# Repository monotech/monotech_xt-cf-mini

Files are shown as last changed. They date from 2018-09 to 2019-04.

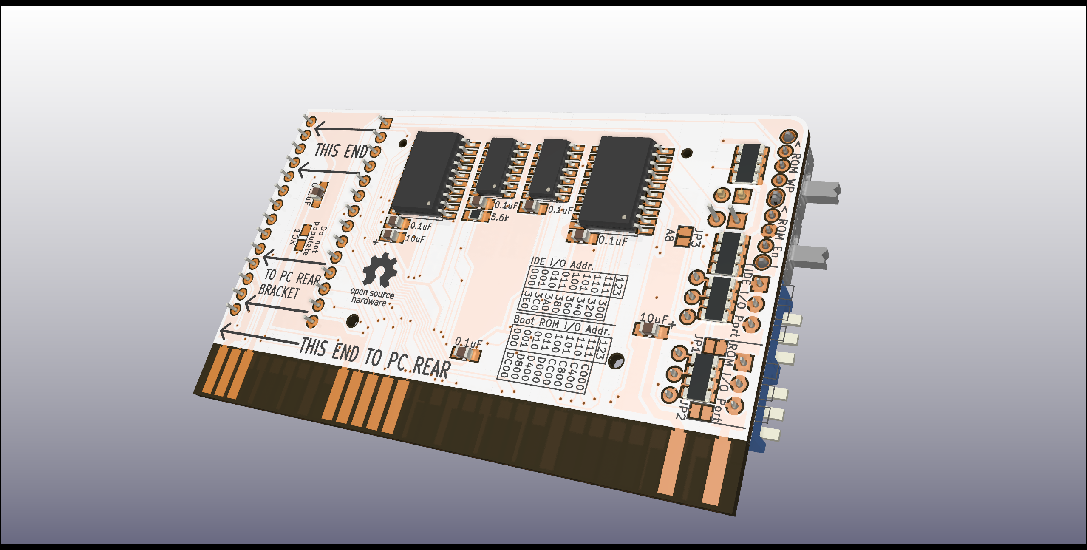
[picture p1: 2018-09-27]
Images/Rear with some parts models.png

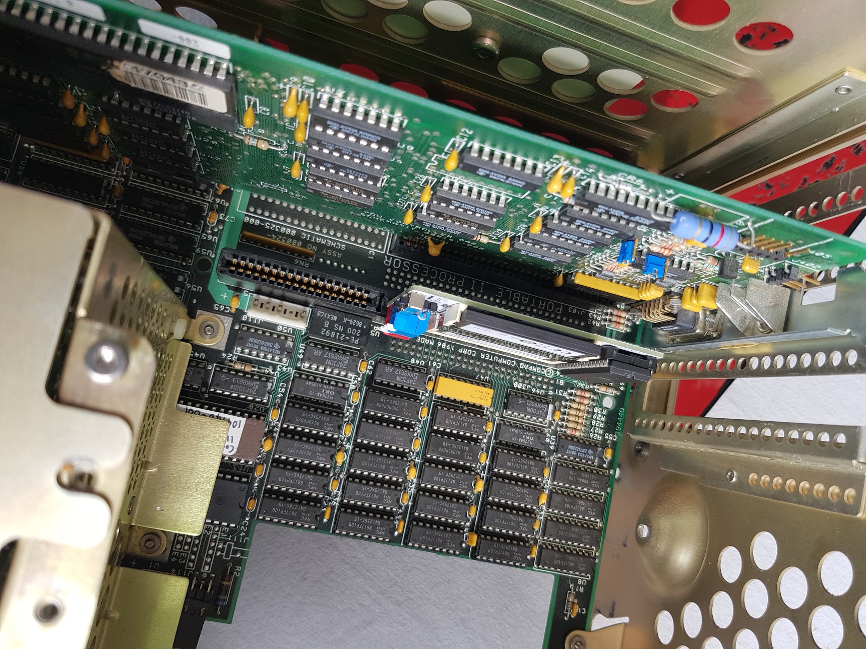
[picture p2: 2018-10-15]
Photos/In motherboard - top.jpg

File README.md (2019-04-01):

Monotech XT-CF-Mini Rev1.1 ReadMe
----------------------------

8-bit ISA CompactFlash interface + Boot ROM (two separate functions that can be used individually).

Documentation for the switches can be found on the rear silkscreen. More ROM I/O addresses are possible than the information on the silkscreen. See below.

Credit:
-------
Design uses schematic from Sergey Kiselev, with a few small changes to switches, and PCB from scratch.\
www.malinov.com/Home/sergeys-projects/xt-cf-lite

XT-IDE Universal BIOS\
www.xtideuniversalbios.org  
www.xtideuniversalbios.org/binaries  
Use the latest working binary that includes XTIDECFG.COM (config utility), ide_xt.bin (8086/8088), ide_xtp.bin (80186/V20/V30 and up).

Further documentation:
----------------------

SW1 - ON: ROM Enabled; OFF: ROM Disabled\
SW2 - ON: EEPROM Write Enabled; OFF: EEPROM Write Disabled

---

SW3 - ROM I/O Port:  
123 ROM  
111 C0000  
111 C2000*  
110 C4000  
110 C6000*  
101 C8000  
101 CA000  
100 CC000  
100 CE000*  
011 D0000 < Default  
011 D2000*  
010 D4000  
010 D6000*  
001 D8000  
001 DA000*  
000 DC000  
000 DE000*  
111 E0000**  
111 E2000***  
110 E4000**  
110 E6000***  
101 E8000**  
101 EA000***  
100 EC000**  
100 EE000***  
011 F0000**  
011 F2000***  
010 F4000**  

Settings marked with asterisks require solder-jumpers to be opened:

Settings marked with * require JP1 to be opened.\
Settings marked with ** require JP2 to be opened.\
Settings marked with *** require both JP1 and JP2 to be opened.\
Settings marked with no *, are set with the three DIP switches, and require JP1 and JP2 to be closed.\

Make sure that selected I/O and EEPROM addresses do not conflict with other devices.\
Addresses 0xC0000 - 0xC6000 will conflict with EGA/VGA BIOS extension.\
Addresses 0xC8000 - 0xCA000 might conflict with XT Hard Disk BIOS extension.\
Addresses 0xE0000 and up might conflict with system BIOS on newer motherboards.\
It is recommended to disable EEPROM write once XT IDE BIOS extension is programmed and configured.

---

SW4 - IDE I/O Port:  
123 IDE  
111 300 < Default  
011 320  
101 340  
001 360  
110 380  
010 3A0  
100 3C0  
000 3E0  

The A8 line is provided as a solder-jumper JP3, and should change the first digit of the IDE I/O Port from 3 to 2 (so 300 becomes 200, 3C0 becomes 2C0, etc). This is untested at present.\

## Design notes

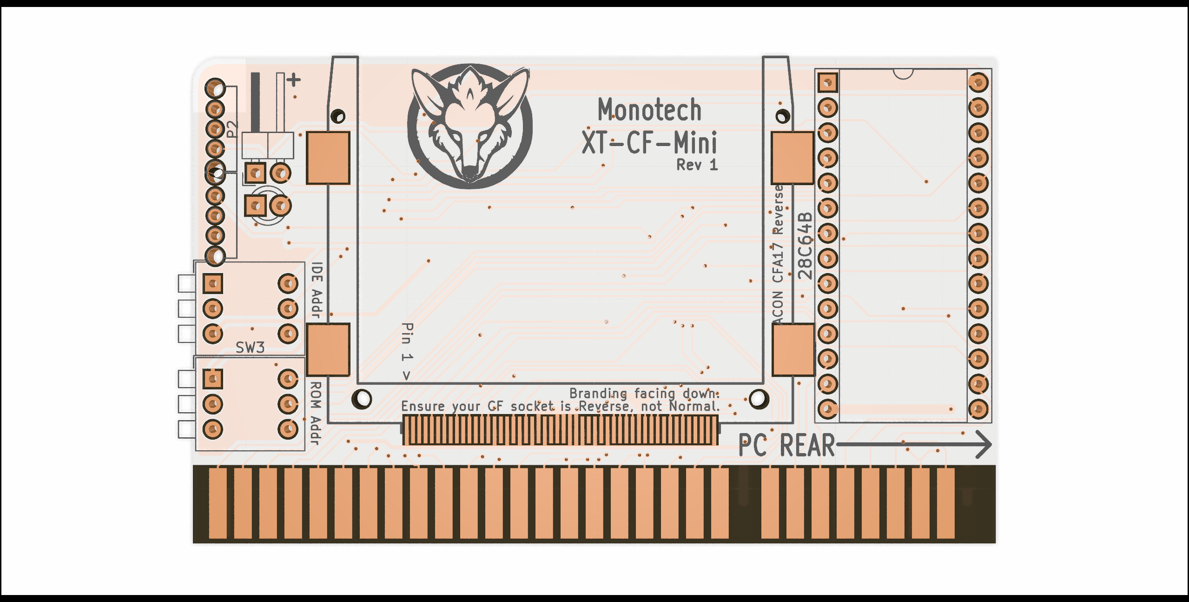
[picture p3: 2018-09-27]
Images/Front bare.png

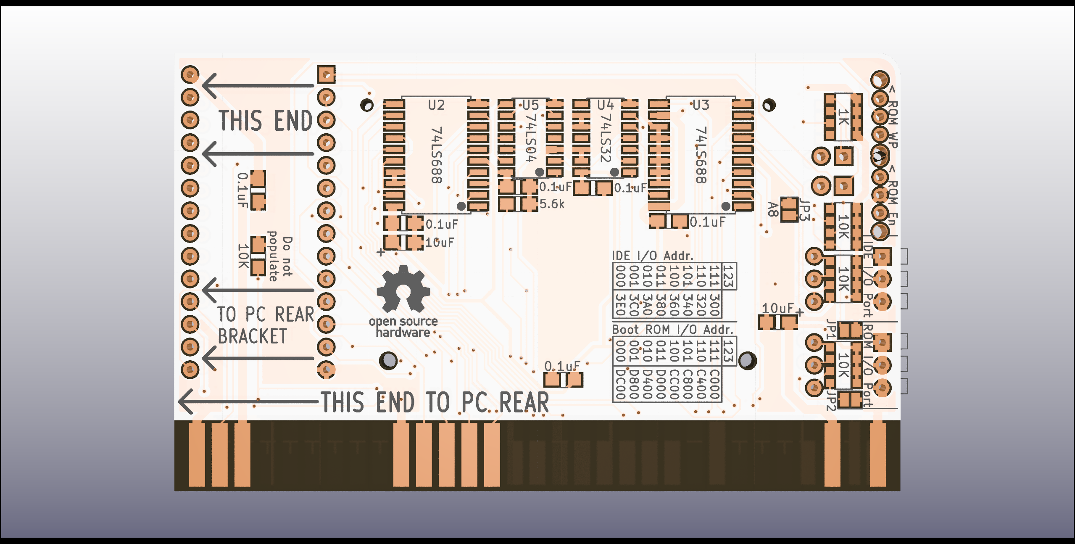
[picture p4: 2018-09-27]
Images/Rear bare.png

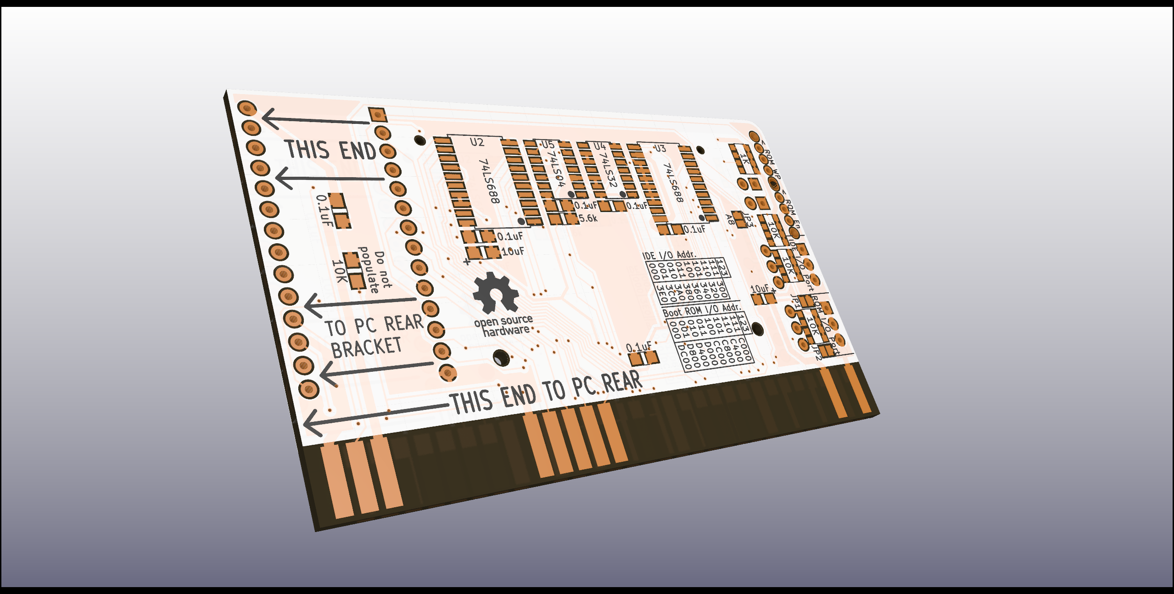
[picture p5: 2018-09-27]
Images/Rear profile.png

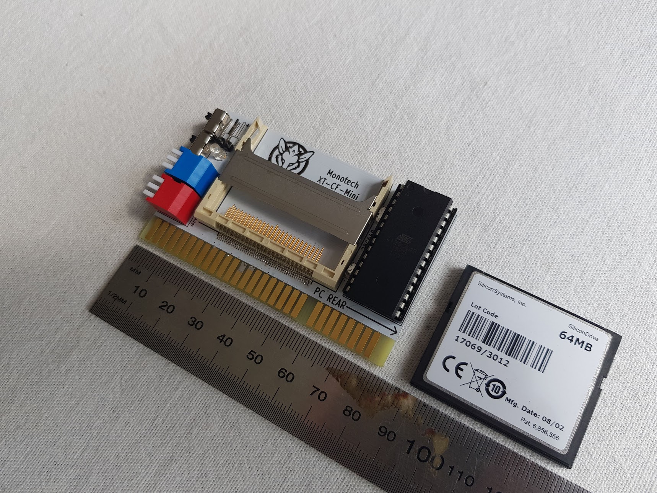
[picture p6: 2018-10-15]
Photos/Profile.jpg

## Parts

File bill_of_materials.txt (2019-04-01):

Monotech XT-CF-Mini rev 1 Bill of Materials
---------------------------------------
Ref(s)		Value
-------------------------------------------
U1		AT28C64B DIP-28 (EEPROM)
U2-U3		74HCT688 SOIC-20 7.52mm
U4		74HCT32 SOIC-14
U5		74HCT04 SOIC-14
SW1-SW2		SPDT Slide Switch, right angle (CnK OS102011MA1QN1)
SW3-SW4		3-position DIP Switch (Piano, 2.54mm) (Best to get two colours; piano style is optional)
RN1-RN3		10K x 4 Isolated Resistor Array - 4x1206 SMD
RN4		1K x 4 Isolated Resistor Array - 4x1206 SMD
R1		5.6K 0805 SMD Resistor
D1		3mm LED
P1		3M N7E50-7516TS0884 CF Card Socket
C1-C6		10 - 100nF  0805 SMD Capacitor
C7-C8		10uF 0805 SMD Capacitor
SOCKET		28-pin IC Socket (wide type) (for EEPROM)

Note:	All 7400 series logic ICs can be substituted for LS, ALS, ACT, F, or HCT equivalents.
	74*688 and 74*521 are identical ICs. Locally, Texas Instruments 74F521 is cheapest for some reason so I use those.
	PCB can be adjusted for more common CF card types; I just had a bunch of these to use.

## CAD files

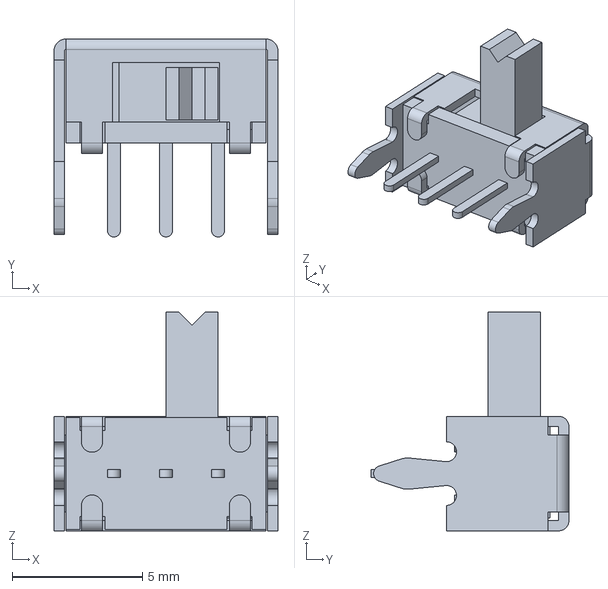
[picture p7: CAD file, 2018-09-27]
3Dmodels/OS102011MA1QN1.stp
8.60 x 7.60 x 8.40 mm

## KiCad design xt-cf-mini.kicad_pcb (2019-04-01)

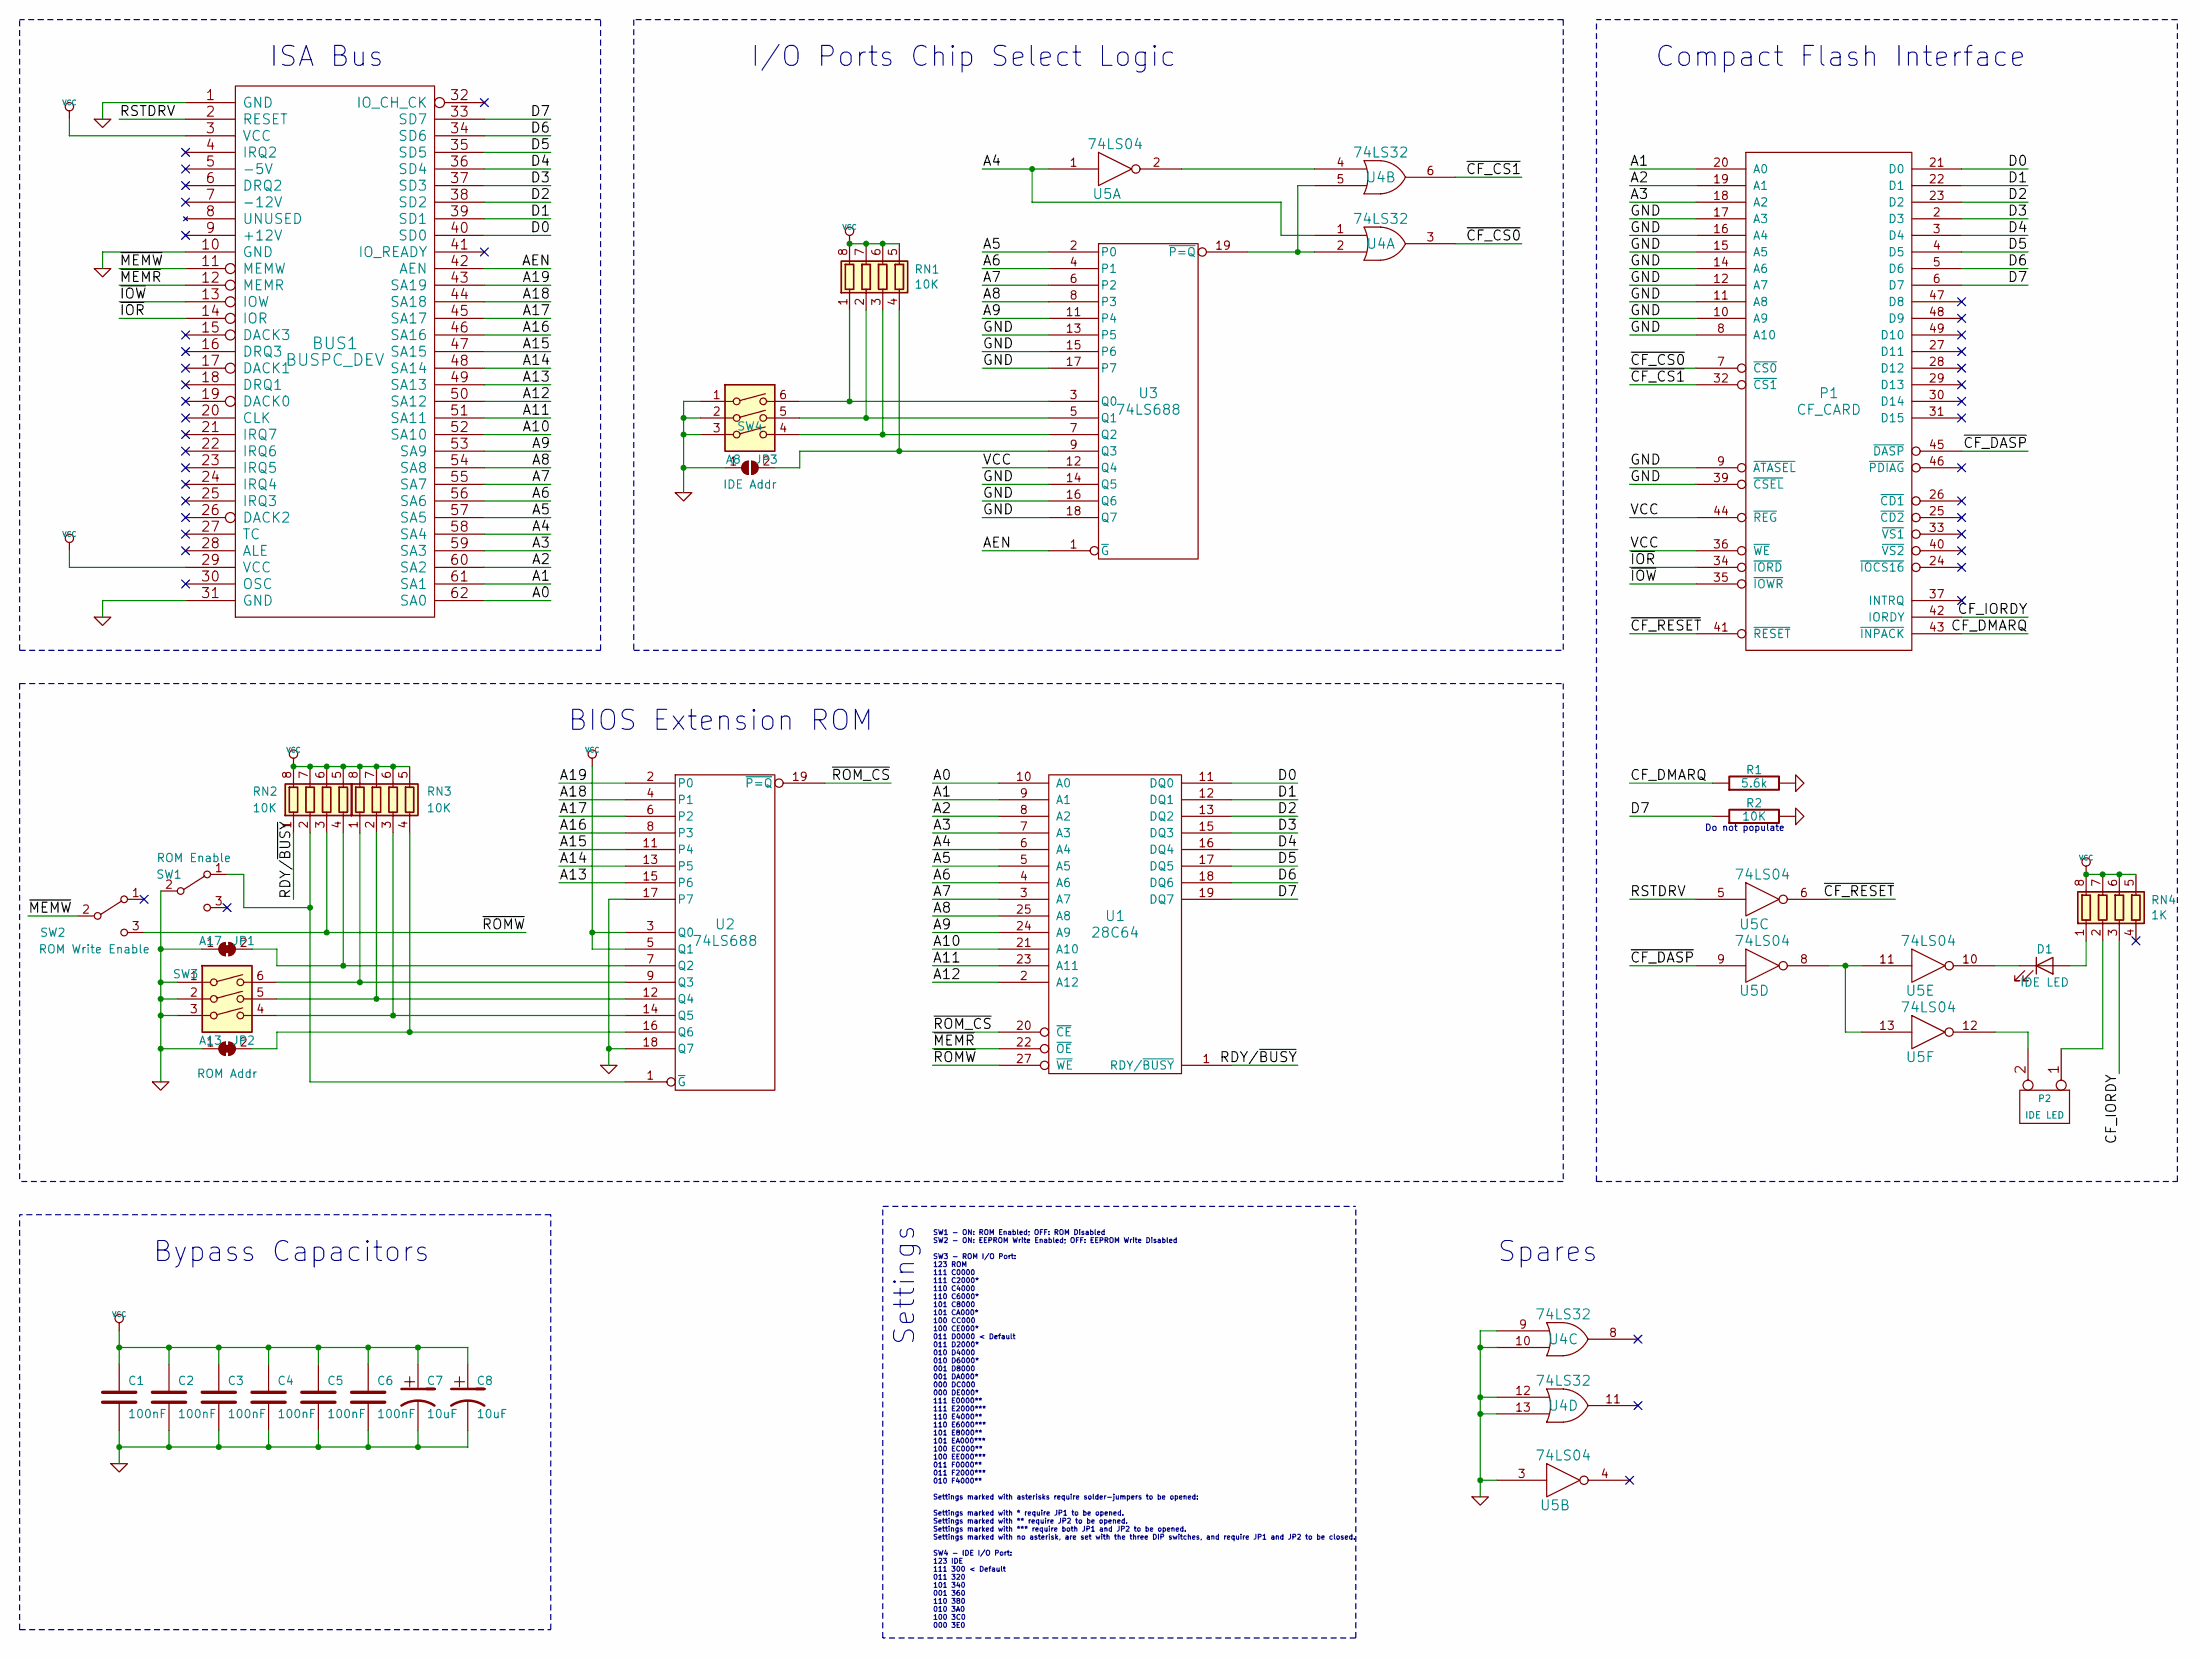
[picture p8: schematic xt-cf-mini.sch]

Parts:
BUS1: BUSPC_DEV; ISA-8BIT-XT-CF
C1, C2, C3, C4, C5, C6: 100nF; C_0805_2012Metric_Pad1.15x1.40mm_HandSolder
C7, C8: 10uF; C_0805_2012Metric_Pad1.15x1.40mm_HandSolder
D1: IDE LED; LED_D3.0mm
JP1: A17; SolderJumper-2_P1.3mm_Open_Pad1.0x1.5mm
JP2: A13; SolderJumper-2_P1.3mm_Open_Pad1.0x1.5mm
JP3: A8; SolderJumper-2_P1.3mm_Open_Pad1.0x1.5mm
P1: CF_CARD; CF_Slot_3M_N7E50-7516TS0884
P2: IDE LED; PinHeader_1x02_P2.54mm_Horizontal
R1: 5.6k; C_0805_2012Metric_Pad1.15x1.40mm_HandSolder
R2: 10K; C_0805_2012Metric_Pad1.15x1.40mm_HandSolder
RN1, RN2, RN3: 10K; R_Array_Convex_4x1206
RN4: 1K; R_Array_Convex_4x1206
SW1: ROM Enable; CKCOMP-OS102011MA1QN1
SW2: ROM Write Enable; CKCOMP-OS102011MA1QN1
SW3: ROM Addr; SW_DIP_SPSTx03_Slide_9.78x9.8mm_W7.62mm_P2.54mm
SW4: IDE Addr; SW_DIP_SPSTx03_Slide_9.78x9.8mm_W7.62mm_P2.54mm
U1: 28C64; DIP-28_W15.24mm_Socket
U2, U3: 74LS688; SOIC-20W_7.5x12.8mm_P1.27mm
U4: 74LS32; SOIC-14_3.9x8.7mm_P1.27mm
U5: 74LS04; SOIC-14_3.9x8.7mm_P1.27mm

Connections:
/A0: BUS1.62 (SA0), U1.10 (A0)
/A1: BUS1.61 (SA1), P1.20 (A0), U1.9 (A1)
/A2: BUS1.60 (SA2), P1.19 (A1), U1.8 (A2)
/A3: BUS1.59 (SA3), P1.18 (A2), U1.7 (A3)
/A4: BUS1.58 (SA4), U1.6 (A4), U4.1, U5.1
/A5: BUS1.57 (SA5), U1.5 (A5), U3.2 (P0)
/A6: BUS1.56 (SA6), U1.4 (A6), U3.4 (P1)
/A7: BUS1.55 (SA7), U1.3 (A7), U3.6 (P2)
/A8: BUS1.54 (SA8), U1.25 (A8), U3.8 (P3)
/A9: BUS1.53 (SA9), U1.24 (A9), U3.11 (P4)
/A10: BUS1.52 (SA10), U1.21 (A10)
/A11: BUS1.51 (SA11), U1.23 (A11)
/A12: BUS1.50 (SA12), U1.2 (A12)
/A13: BUS1.49 (SA13), U2.15 (P6)
/A14: BUS1.48 (SA14), U2.13 (P5)
/A15: BUS1.47 (SA15), U2.11 (P4)
/A16: BUS1.46 (SA16), U2.8 (P3)
/A17: BUS1.45 (SA17), U2.6 (P2)
/A18: BUS1.44 (SA18), U2.4 (P1)
/A19: BUS1.43 (SA19), U2.2 (P0)
/AEN: BUS1.42 (AEN), U3.1 (~G)
/CF_DMARQ: P1.43 (~INPACK), R1.1
/CF_IORDY: P1.42 (IORDY), RN4.3 (R3.1)
/D0: BUS1.40 (SD0), P1.21 (D0), U1.11 (DQ0)
/D1: BUS1.39 (SD1), P1.22 (D1), U1.12 (DQ1)
/D2: BUS1.38 (SD2), P1.23 (D2), U1.13 (DQ2)
/D3: BUS1.37 (SD3), P1.2 (D3), U1.15 (DQ3)
/D4: BUS1.36 (SD4), P1.3 (D4), U1.16 (DQ4)
/D5: BUS1.35 (SD5), P1.4 (D5), U1.17 (DQ5)
/D6: BUS1.34 (SD6), P1.5 (D6), U1.18 (DQ6)
/D7: BUS1.33 (SD7), P1.6 (D7), R2.1, U1.19 (DQ7)
/RDY/~BUSY: RN2.1 (R1.1), U1.1 (RDY/~BUSY)
/RSTDRV: BUS1.2 (RESET), U5.5
/~CF_CS0: P1.7 (~CS0), U4.3
/~CF_CS1: P1.32 (~CS1), U4.6
/~CF_DASP: P1.45 (~DASP), U5.9
/~CF_RESET: P1.41 (~RESET), U5.6
/~IOR: BUS1.14 (IOR), P1.34 (~IORD)
/~IOW: BUS1.13 (IOW), P1.35 (~IOWR)
/~MEMR: BUS1.12 (MEMR), U1.22 (~OE)
/~MEMW: BUS1.11 (MEMW), SW2.2 (B)
/~ROMW: RN2.3 (R3.1), SW2.3 (C), U1.27 (~WE)
/~ROM_CS: U1.20 (~CE), U2.19 (~P=Q)
GND: BUS1.1 (GND), BUS1.10 (GND), BUS1.31 (GND), C1.2, C2.2, C3.2, C4.2, C5.2, C6.2, C7.2, C8.2, JP1.1 (A), JP2.1 (A), JP3.1 (A), P1.1 (GND), P1.8 (A10), P1.9 (~ATASEL), P1.10 (A9), P1.11 (A8), P1.12 (A7), P1.14 (A6), P1.15 (A5), P1.16 (A4), P1.17 (A3), P1.39 (~CSEL), P1.50 (GND), R1.2, R2.2, SW1.2 (B), SW3.1, SW3.2, SW3.3, SW4.1, SW4.2, SW4.3, U1.14 (GND), U2.10 (GND), U2.17 (P7), U2.18 (Q7), U3.10 (GND), U3.13 (P5), U3.14 (Q5), U3.15 (P6), U3.16 (Q6), U3.17 (P7), U3.18 (Q7), U4.7 (GND), U4.9, U4.10, U4.12, U4.13, U5.3, U5.7 (GND)
unnamed: D1.1 (K), U5.10
unnamed: D1.2 (A), RN4.1 (R1.1)
unnamed: JP1.2 (B), RN2.4 (R4.1), U2.7 (Q2)
unnamed: JP2.2 (B), RN3.4 (R4.1), U2.16 (Q6)
unnamed: JP3.2 (B), RN1.4 (R4.1), U3.9 (Q3)
unnamed: P2.1, RN4.2 (R2.1)
unnamed: P2.2 (PM), U5.12
unnamed: RN1.1 (R1.1), SW4.6, U3.3 (Q0)
unnamed: RN1.2 (R2.1), SW4.5, U3.5 (Q1)
unnamed: RN1.3 (R3.1), SW4.4, U3.7 (Q2)
unnamed: RN2.2 (R2.1), SW1.1 (A), U2.1 (~G)
unnamed: RN3.1 (R1.1), SW3.6, U2.9 (Q3)
unnamed: RN3.2 (R2.1), SW3.5, U2.12 (Q4)
unnamed: RN3.3 (R3.1), SW3.4, U2.14 (Q5)
unnamed: U3.19 (~P=Q), U4.2, U4.5
unnamed: U4.4, U5.2
unnamed: U5.8, U5.11, U5.13
VCC: BUS1.3 (VCC), BUS1.29 (VCC), C1.1, C2.1, C3.1, C4.1, C5.1, C6.1, C7.1, C8.1, P1.13 (VCC), P1.36 (~WE), P1.38 (VCC), P1.44 (~REG), RN1.5 (R4.2), RN1.6 (R3.2), RN1.7 (R2.2), RN1.8 (R1.2), RN2.5 (R4.2), RN2.6 (R3.2), RN2.7 (R2.2), RN2.8 (R1.2), RN3.5 (R4.2), RN3.6 (R3.2), RN3.7 (R2.2), RN3.8 (R1.2), RN4.5 (R4.2), RN4.6 (R3.2), RN4.7 (R2.2), RN4.8 (R1.2), U1.28 (VCC), U2.3 (Q0), U2.5 (Q1), U2.20 (VCC), U3.12 (Q4), U3.20 (VCC), U4.14 (VCC), U5.14 (VCC)

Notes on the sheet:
Spares
ISA Bus
BIOS Extension ROM
Bypass Capacitors
I/O Ports Chip Select Logic
Compact Flash Interface
SW1 - ON: ROM Enabled; OFF: ROM Disabled SW2 - ON: EEPROM Write Enabled; OFF: EEPROM Write Disabled SW3 - ROM I/O Port: 123 ROM 111 C0000 111 C2000* 110 C4000 110 C6000* 101 C8000 101 CA000* 100 CC000 100 CE000* 011 D0000 < Default 011 D2000* 010 D4000 010 D6000* 001 D8000 001 DA000* 000 DC000 000 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
Settings
Do not populate

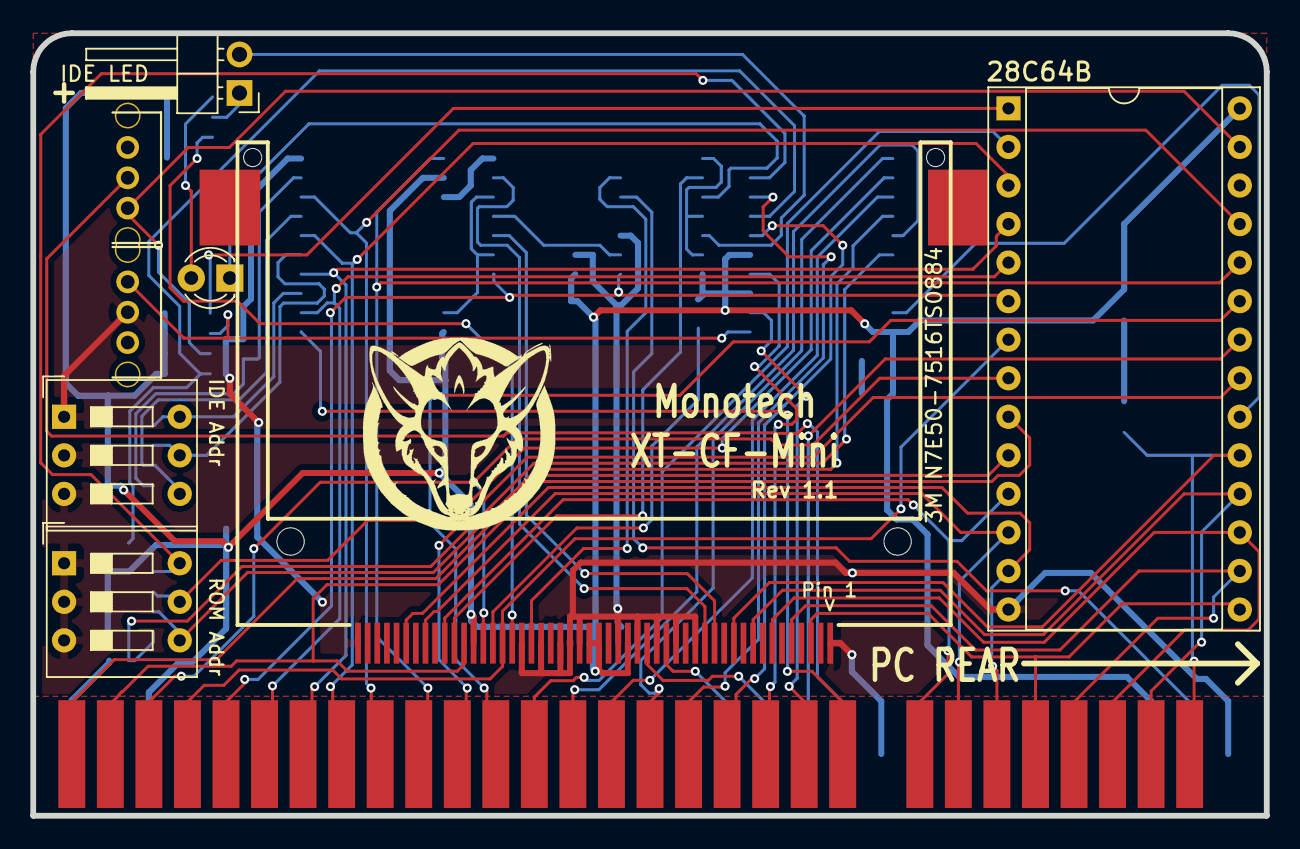
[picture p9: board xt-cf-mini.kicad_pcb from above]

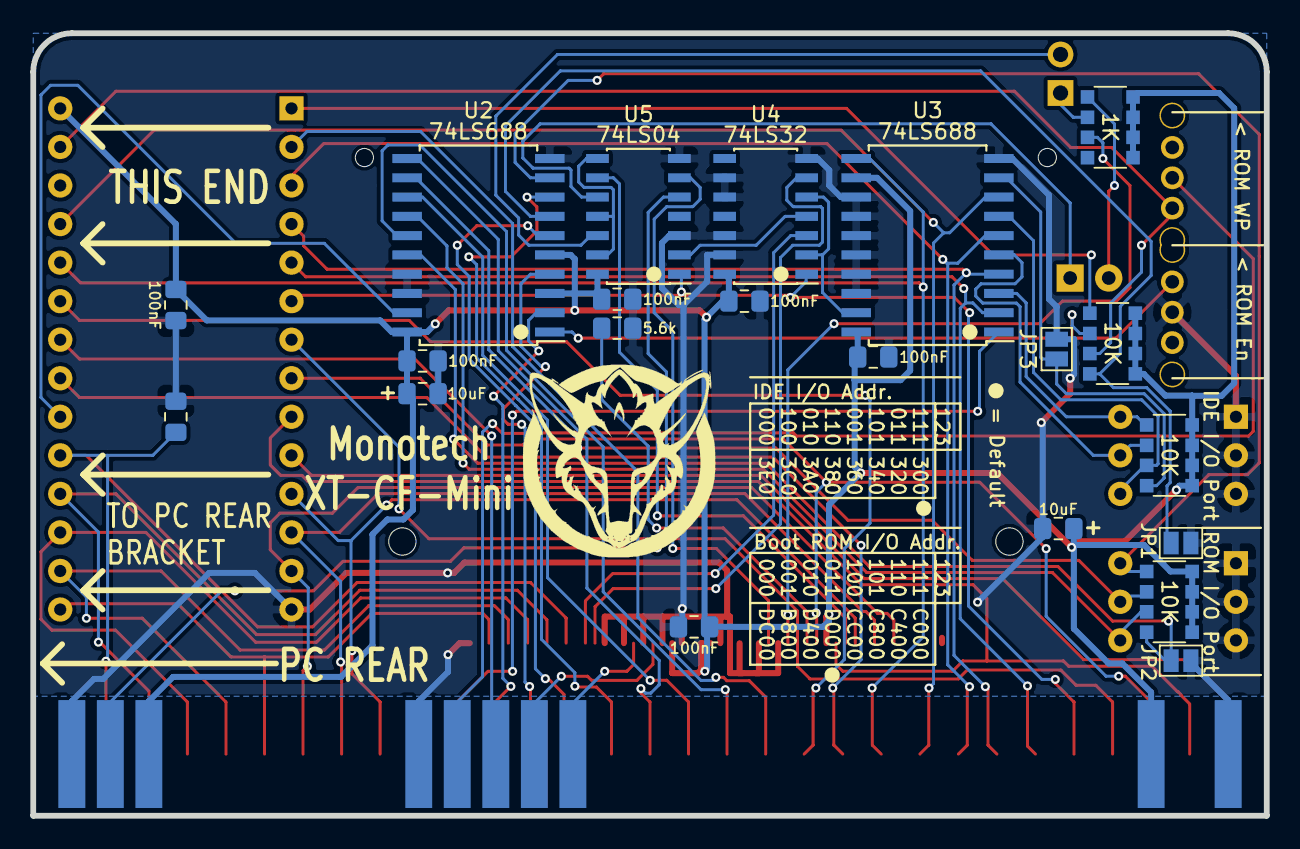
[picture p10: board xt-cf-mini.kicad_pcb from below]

Board: 2 copper layers, 81.3 x 51.6 mm, 30 parts (21 on the bottom side), 62 nets.

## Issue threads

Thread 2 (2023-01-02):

Is Rev 1.1 using normal or reversed CF socket?

TzOk83, 2023-01-02:
Silkscreen suggests normal CF socket (pin 1 on the right), while renders and photos show reversed CF socket (pin 1 on the left, CF card inserted with label facing the PCB).

TzOk83, 2023-01-04:
I'll answer to myself - the 3M version (Rev 1.1) uses a regular CompactFlash socket, with mounting hole raster of 40.16mm, eg. MOLEX 0671550002.

Closed 2023-01-04.

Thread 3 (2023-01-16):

BOM needs correcting

SanguineBrah, 2023-01-16:
The part number for the CF card socket on the BOM is incorrect. The last four digits are a document id number for a datasheet, but it is the datasheet for the socket used on version 1, which used a reverse socket whereas 1.1 does not use a reverse socket. The part number is also incorrect on the silkscreen.

A compatible, non-obsolete socket for version 1.1 is N7E50-M516RB-50-WF.

It would also be helpful for the resistor arrays to use the package description which is given by most parts suppliers (2021 or 5030 metric).

prabathbr, 2023-06-07:
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

Thanks a lot for the model number "N7E50-M516RB-50-WF". Just to make sure are you using this CF socket with "[XT-CF-Mini 3M.zip" or "Monotech XT-CF-Mini Rev1.zip" under gerber folder ?

SanguineBrah, 2023-06-07:
> Just to make sure are you using this CF socket with "[XT-CF-Mini 3M.zip" or "Monotech XT-CF-Mini Rev1.zip" under gerber folder ?

This is with "XT-CF-Mini 3M.zip".

prabathbr, 2023-06-09:
> > Just to make sure are you using this CF socket with "[XT-CF-Mini 3M.zip" or "Monotech XT-CF-Mini Rev1.zip" under gerber folder ?
>
> This is with "XT-CF-Mini 3M.zip".

Thanks a lot for the help!
